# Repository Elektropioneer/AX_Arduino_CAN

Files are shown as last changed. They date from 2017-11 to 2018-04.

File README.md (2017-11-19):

# AX_Arduino_CAN
Driver for Arduino Nano to control AX.
Communication protocol is CAN to connect it to our robot communication system. 
There are pinouts for I2C to easily connect Arduino supported sensors.




Schematic

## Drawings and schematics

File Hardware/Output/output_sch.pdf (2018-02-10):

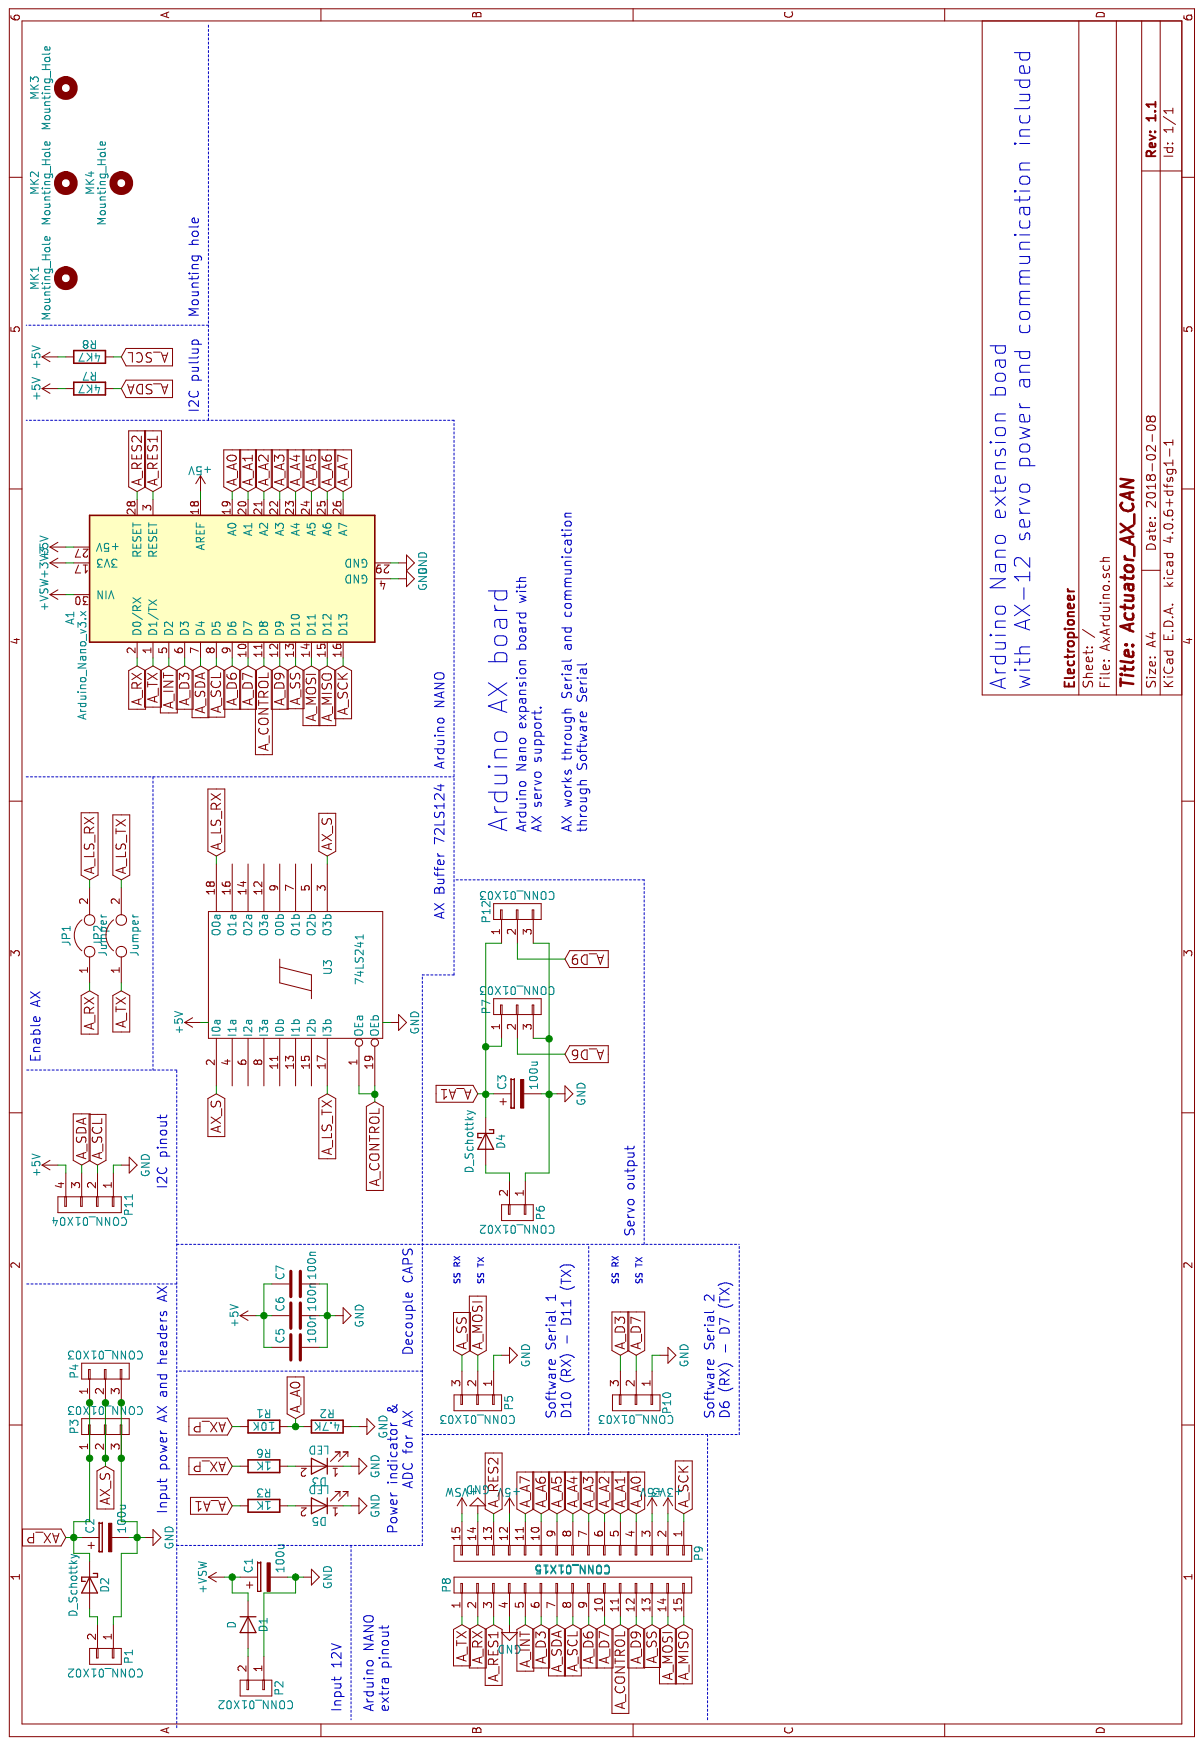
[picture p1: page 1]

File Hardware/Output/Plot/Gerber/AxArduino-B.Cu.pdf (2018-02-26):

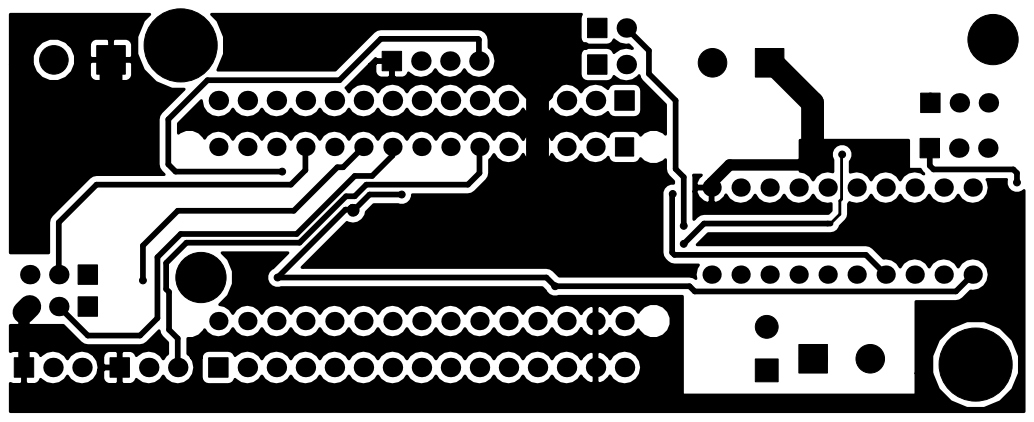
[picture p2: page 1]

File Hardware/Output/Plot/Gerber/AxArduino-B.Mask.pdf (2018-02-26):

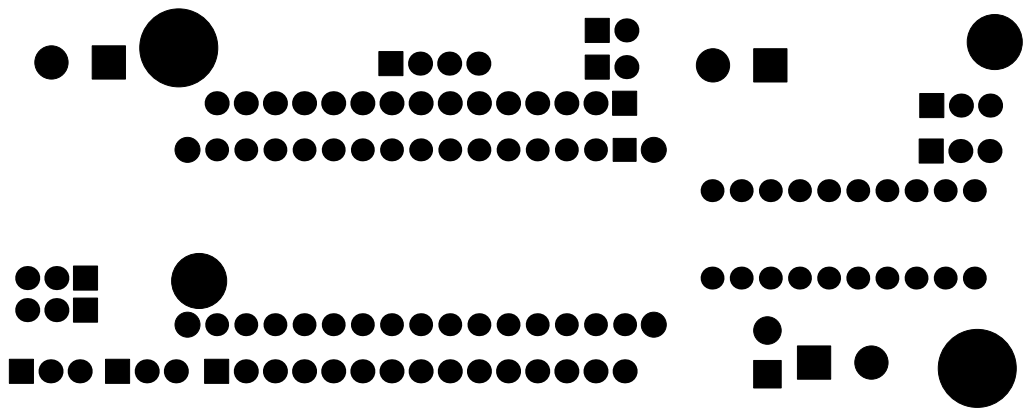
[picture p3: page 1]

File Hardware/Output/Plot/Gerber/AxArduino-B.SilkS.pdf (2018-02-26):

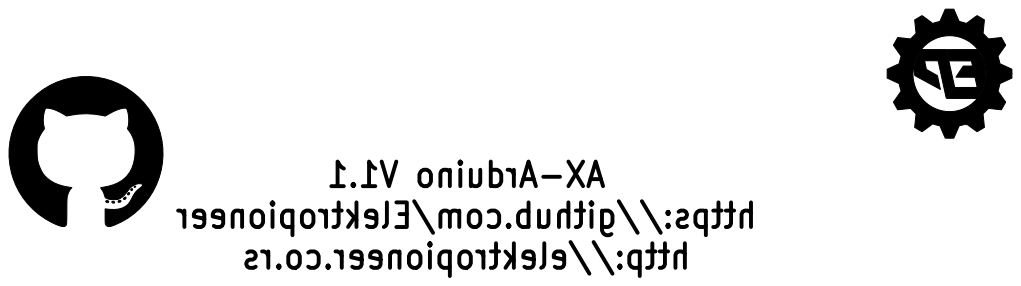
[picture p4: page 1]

https://github.com/Elektropioneer

http://elektropioneer.co.rs

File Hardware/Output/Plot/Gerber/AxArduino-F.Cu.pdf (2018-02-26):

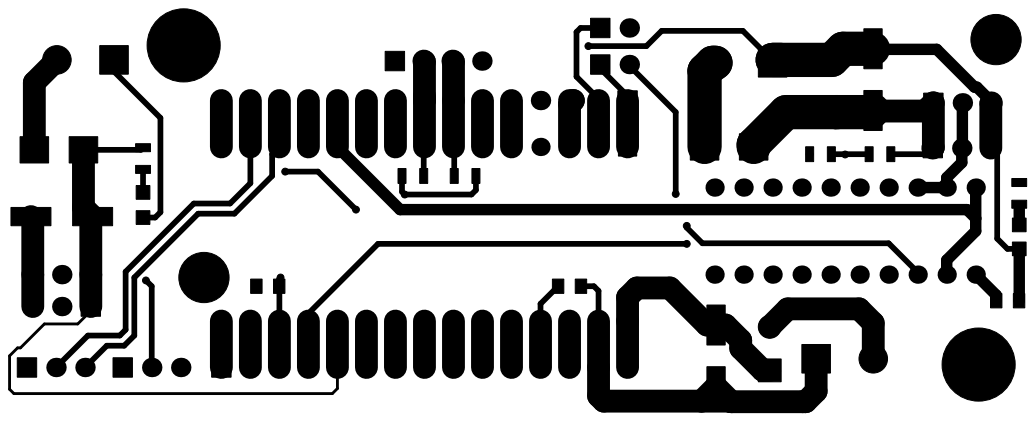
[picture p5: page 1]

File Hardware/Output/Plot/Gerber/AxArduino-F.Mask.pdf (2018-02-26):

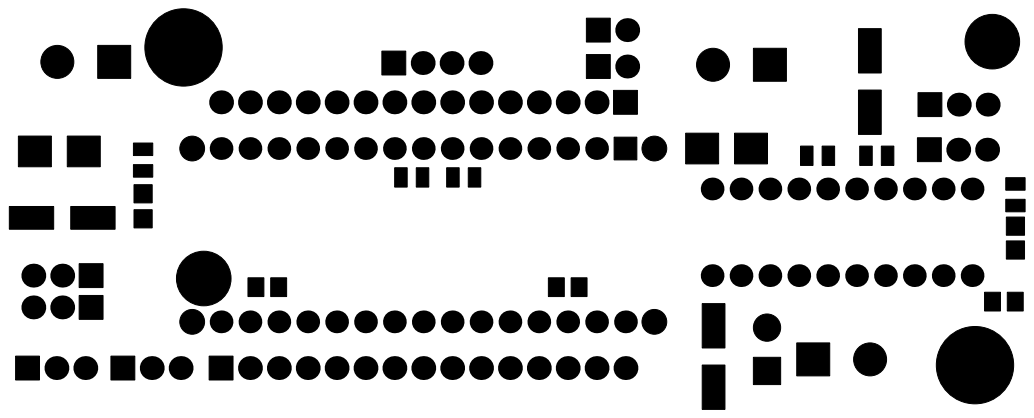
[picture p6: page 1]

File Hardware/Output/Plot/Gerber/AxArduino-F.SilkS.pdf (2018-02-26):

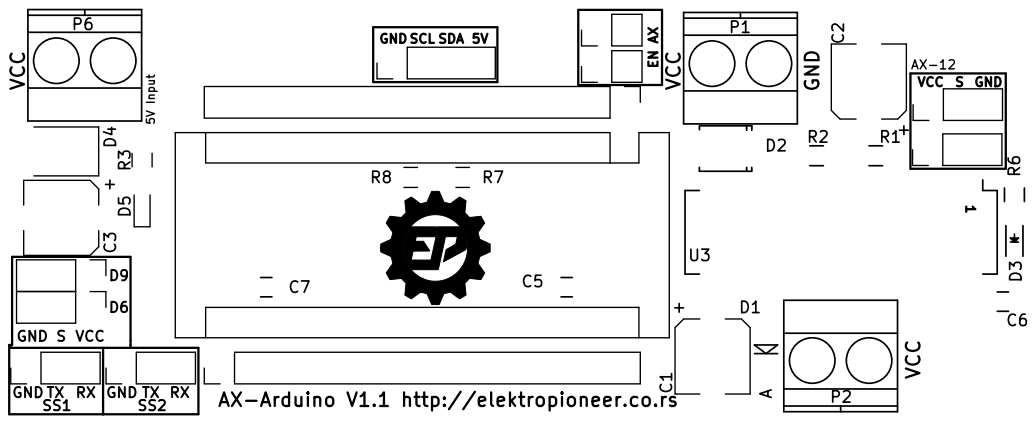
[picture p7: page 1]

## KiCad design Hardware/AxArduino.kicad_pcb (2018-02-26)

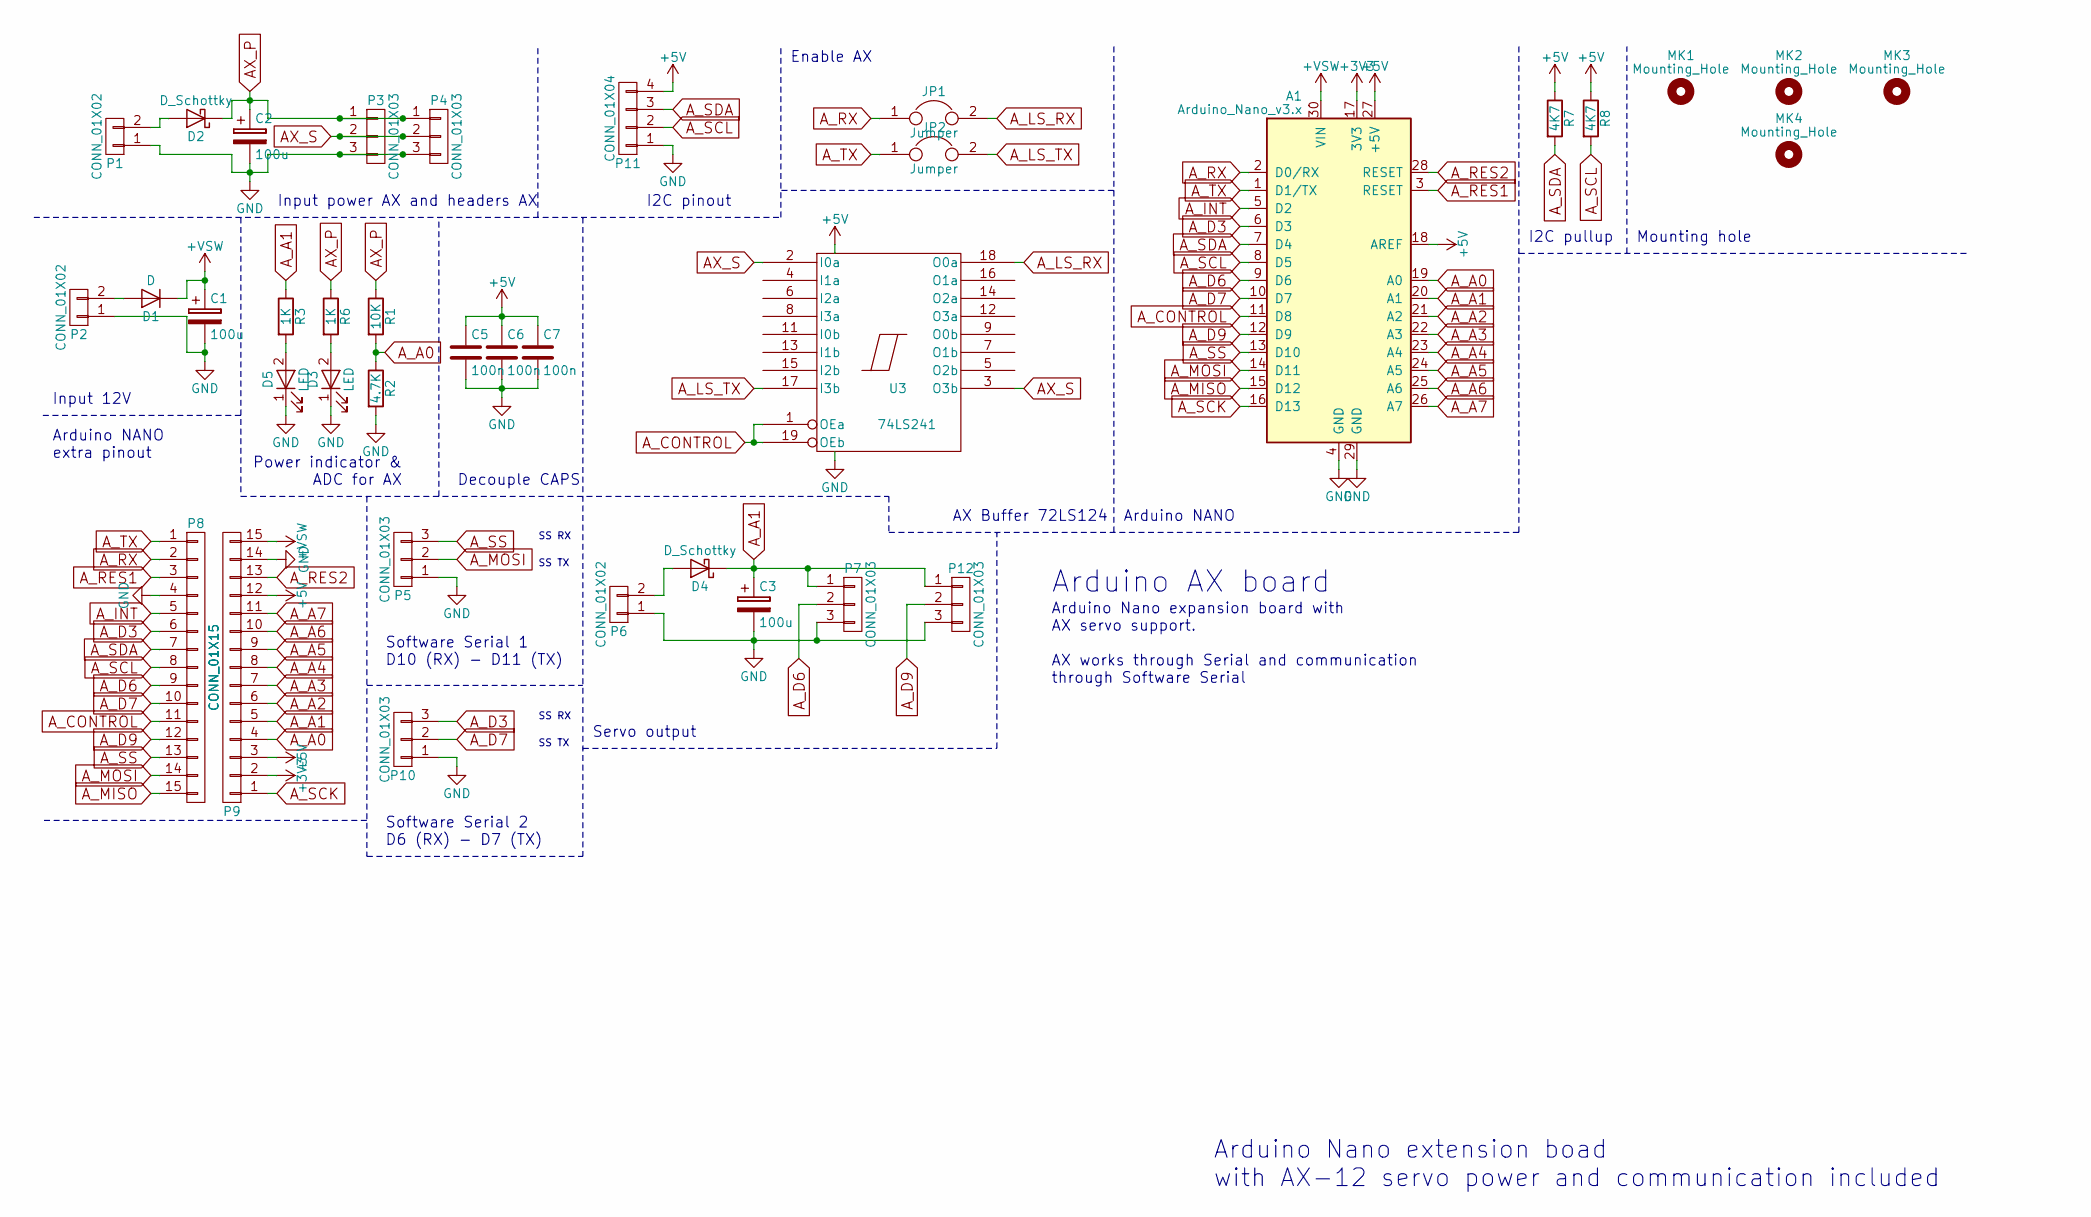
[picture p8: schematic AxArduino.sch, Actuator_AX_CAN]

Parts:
A1: Arduino_Nano_v3.x; Arduino_Nano_WithMountingHoles
C1, C2, C3: 100u; CP_Elec_6.3x5.3
C5, C6, C7: 100n; C_0805
D1: D; Diode_DO-41_SOD81_Vertical_AnodeUp
D2: D_Schottky; SMB_Standard
D3, D5: LED; LED_0805
D4: D_Schottky; D_SMB_Standard
JP1, JP2: Jumper; Pin_Header_Straight_1x02_Pitch2.54mm
MK1, MK2: Mounting_Hole; MountingHole_3.2mm_M3_Pad_Via
MK3, MK4: Mounting_Hole; MountingHole_2.2mm_M2_Pad
P1, P2, P6: CONN_01X02; TerminalBlock_Pheonix_MKDS1.5-2pol
P3, P4, P5, P7, P10, P12: CONN_01X03; Pin_Header_Straight_1x03_Pitch2.54mm
P8, P9: CONN_01X15; Pin_Header_Straight_1x15_Pitch2.54mm
P11: CONN_01X04; Pin_Header_Straight_1x04_Pitch2.54mm
R1: 10K; R_0805
R2: 4.7K; R_0805
R3, R6: 1K; R_0805
R7, R8: 4K7; R_0805
U3: 74LS241; DIP-20_W7.62mm

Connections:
+3V3: A1.17 (3V3), P9.2
+5V: A1.18 (AREF), A1.27 (+5V), C5.1, C6.1, C7.1, P9.3, P9.12, P11.4, R7.1, R8.1, U3.20 (VCC)
+VSW: A1.30 (VIN), C1.1, D1.1 (K), P9.15
AX_P: C2.1, D2.1 (K), P3.1, P4.1, R1.1, R6.1
AX_S: P3.2, P4.2, U3.2 (I0a), U3.3 (O3b)
A_A0: A1.19 (A0), P9.4, R1.2, R2.1
A_A1: A1.20 (A1), C3.1, D4.1 (K), P7.1, P9.5, P12.1, R3.1
A_A2: A1.21 (A2), P9.6
A_A3: A1.22 (A3), P9.7
A_A4: A1.23 (A4), P9.8
A_A5: A1.24 (A5), P9.9
A_A6: A1.25 (A6), P9.10
A_A7: A1.26 (A7), P9.11
A_CONTROL: A1.11 (D8), P8.11, U3.1 (OEa), U3.19 (OEb)
A_D3: A1.6 (D3), P8.6, P10.3
A_D6: A1.9 (D6), P7.2, P8.9
A_D7: A1.10 (D7), P8.10, P10.2
A_D9: A1.12 (D9), P8.12, P12.2
A_INT: A1.5 (D2), P8.5
A_LS_RX: JP1.2, U3.18 (O0a)
A_LS_TX: JP2.2, U3.17 (I3b)
A_MISO: A1.15 (D12), P8.15
A_MOSI: A1.14 (D11), P5.2, P8.14
A_RES1: A1.3 (RESET), P8.3
A_RES2: A1.28 (RESET), P9.13
A_RX: A1.2 (D0/RX), JP1.1, P8.2
A_SCK: A1.16 (D13), P9.1
A_SCL: A1.8 (D5), P8.8, P11.2, R8.2
A_SDA: A1.7 (D4), P8.7, P11.3, R7.2
A_SS: A1.13 (D10), P5.3, P8.13
A_TX: A1.1 (D1/TX), JP2.1, P8.1
GND: A1.4 (GND), A1.29 (GND), C1.2, C2.2, C3.2, C5.2, C6.2, C7.2, D3.1 (K), D5.1 (K), P1.1, P2.1, P3.3, P4.3, P5.1, P6.1, P7.3, P8.4, P9.14, P10.1, P11.1, P12.3, R2.2, U3.10 (GND)
unnamed: D1.2 (A), P2.2
unnamed: D2.2 (A), P1.2
unnamed: D3.2 (A), R6.2
unnamed: D4.2 (A), P6.2
unnamed: D5.2 (A), R3.2

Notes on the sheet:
Input power AX and headers AX
I2C pinout
AX Buffer 72LS124
Decouple CAPS
Power indicator & ADC for AX
Input 12V
Arduino NANO
Arduino NANO extra pinout
Enable AX
I2C pullup
SS RX
SS TX
Software Serial 1 D10 (RX) - D11 (TX)
Arduino Nano extension boad with AX-12 servo power and communication included
Servo output
Arduino AX board
Arduino Nano expansion board with AX servo support. AX works through Serial and communication through Software Serial
Software Serial 2 D6 (RX) - D7 (TX)
Mounting hole

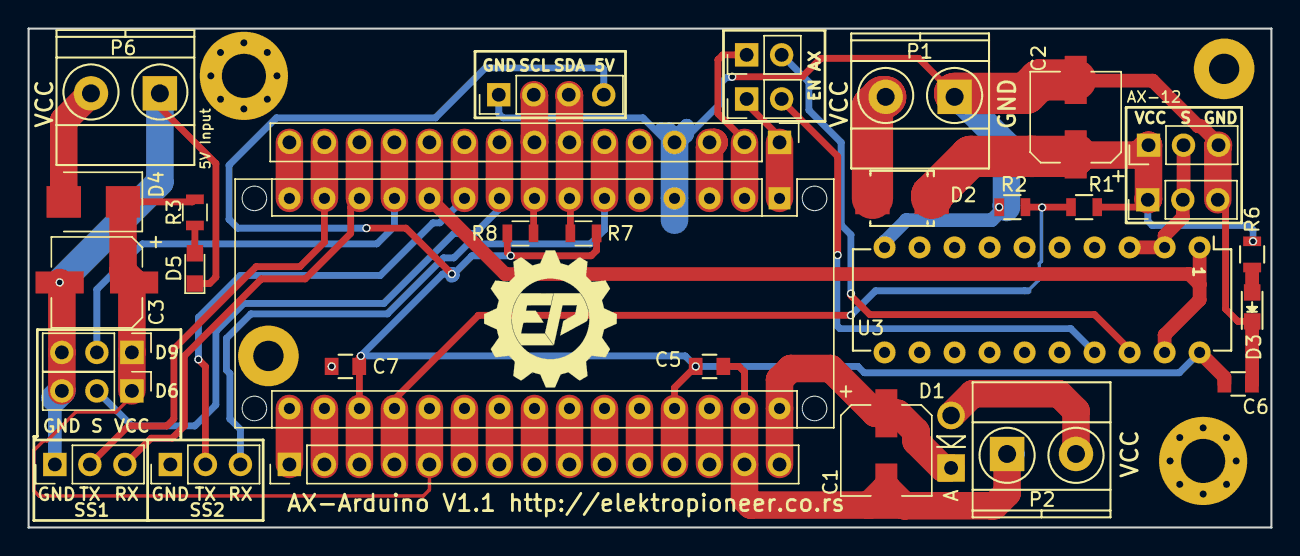
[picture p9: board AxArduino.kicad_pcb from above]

Board: 2 copper layers, 90.2 x 36.2 mm, 37 parts (0 on the bottom side), 37 nets.

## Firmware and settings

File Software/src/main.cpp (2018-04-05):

#include <DynamixelSerial.h>
#include <Arduino.h>
#include <SoftwareSerial.h>
#include <PacketSerial.h>

#define actuatorSSerial_RX         10
#define actuatorSSerial_TX         11
#define actuatorSSerial_Baud       9600


#define Dynamixel_Baud        1000000
#define DIRECTION_PIN        8

PacketSerial ActuatorPacketSerial;

SoftwareSerial actuatorSS(actuatorSSerial_RX, actuatorSSerial_TX);

int x; uint8_t buf[3];

void actuatoronPacketReceived(const uint8_t* buffer, size_t size)
{
  switch(buffer[1]) {

      /*
       * Dynamixel.move(ID, Position);
       */
      case 'm':
        int calc;
        calc = (int)((1024 / 255) * buffer[3]);
        Dynamixel.move(buffer[2], calc);

        break;

      /*
       * Dynamixel.moveSpeed(ID, Position, Speed);
       */
      case 's':
        int calc_angle, calc_speed;
        calc_angle = (int)((1024 / 255) * buffer[3]);
        calc_speed = (int)((1024 / 255) * buffer[4]);
        Dynamixel.moveSpeed(buffer[2], calc_angle, calc_speed);
        break;

      /*
       * Dynamixel.moving(ID)
       */
      case 'M':
        x = Dynamixel.moving(buffer[2]);

        buf[0] = buffer[0];
        buf[1] = buffer[1];
        buf[2] = x;
        ActuatorPacketSerial.send(buf, sizeof(buf)/sizeof(buf)[0]);

        break;

      /*
       * Dynamixel.readPosition(ID);
       */
      case 'p':
        x = Dynamixel.readPosition(buffer[2]);

        buf[0] = buffer[1];
        buf[1] = x >> 8;
        buf[2] = x & 0xFF;
        ActuatorPacketSerial.send(buf, sizeof(buf)/sizeof(buf)[0]);

        break;

      /*
       * Dynamixel.readVoltage(ID)
       */
      case 'v':
        x = Dynamixel.readVoltage(buffer[2]);

        buf[0] = buffer[1];
        buf[1] = x >> 8;
        buf[2] = x & 0xFF;
        ActuatorPacketSerial.send(buf, sizeof(buf)/sizeof(buf)[0]);

        break;

      /*
       * Dynamixel.readTemparature
       */
      case 't':
        x = Dynamixel.readTemperature(buffer[2]);

        buf[0] = buffer[1];
        buf[1] = x >> 8;
        buf[2] = x & 0xFF;
        ActuatorPacketSerial.send(buf, sizeof(buf)/sizeof(buf)[0]);

        break;


    }
}

void setup() {
    Dynamixel.begin(Dynamixel_Baud, DIRECTION_PIN);

    Dynamixel.move(10, Dynamixel.readPosition(10));
    Dynamixel.move(4, Dynamixel.readPosition(4));

    /* ACTUATOR PACKET SERIAL SETUP */
    actuatorSS.begin(actuatorSSerial_Baud);
    ActuatorPacketSerial.setStream(&actuatorSS);
    ActuatorPacketSerial.setPacketHandler(&actuatoronPacketReceived);

}

void loop() {
    ActuatorPacketSerial.update();
}

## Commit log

2017-11-23 Fixed stuff, like moving r to top layer and adding pullups to i2c
    [AxArduino.kicad_pcb, AxArduino.sch]
2017-12-31 New design
    [AxArduino.kicad_pcb, AxArduino.sch]
2018-02-10 Small modifs, added connectors and servo support
    [AxArduino.kicad_pcb, AxArduino.sch]
2018-02-14 Issue: keep out
    [AxArduino.kicad_pcb]
2018-02-26 Added gerber files
    [AxArduino-B.Cu.gbl, AxArduino-B.SilkS.gbo, AxArduino-Edge.Cuts.gko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]
2018-02-26 Files updated, added mask
    [AxArduino-B.Cu.gbl, AxArduino-B.Mask.gbs, AxArduino-B.SilkS.gbo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]
2018-04-02 halfway there ?
    [AxArduino-B.Cu.gbl, AxArduino-B.Mask.gbs, AxArduino-B.SilkS.gbo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]
2018-04-03 Added actuator support, needs testing
